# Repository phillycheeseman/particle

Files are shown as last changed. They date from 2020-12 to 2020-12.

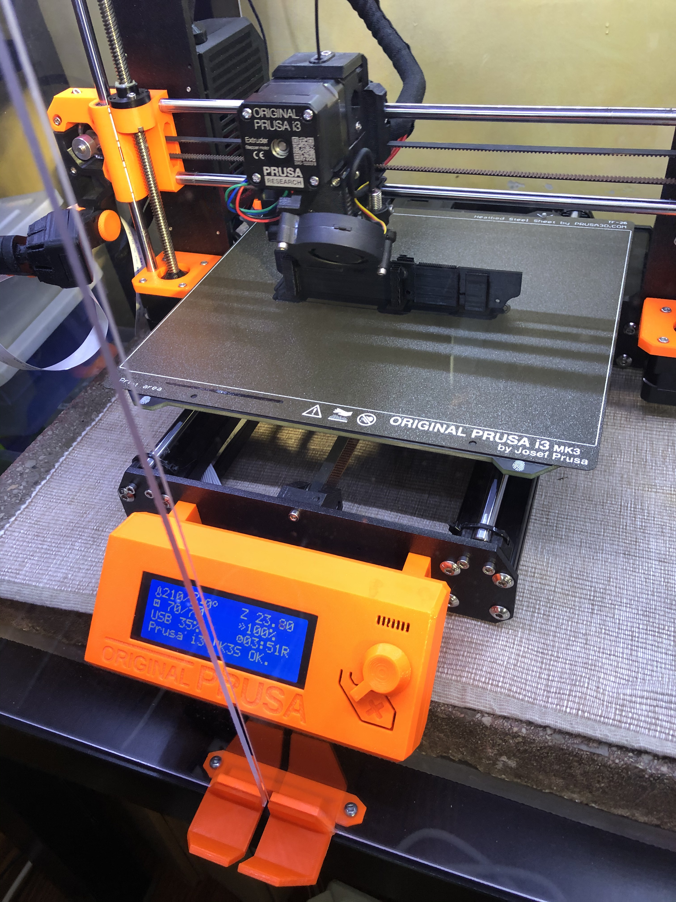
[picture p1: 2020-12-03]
Proto Insert v14/IMG_5619.jpeg

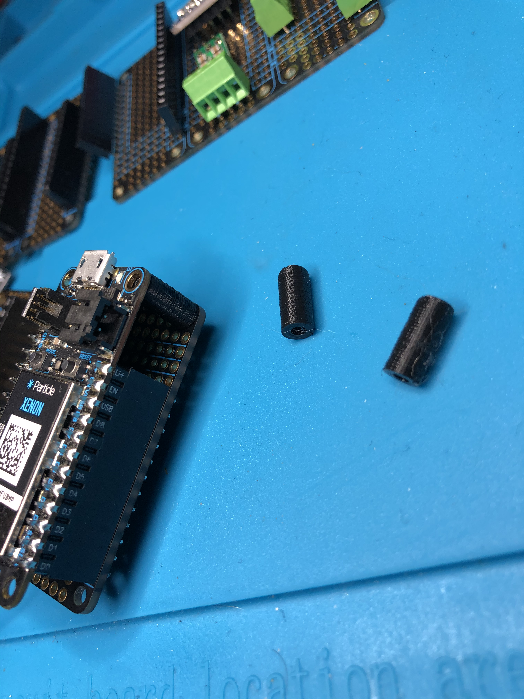
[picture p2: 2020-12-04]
Standoff Spacer/IMG_5630.jpeg

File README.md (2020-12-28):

# particle
Particle.io designs

I am starting this GitHub thread to discuss 3D printing for IoT devices.

There are several project discussions:
- Adapter Plates for commercial Project Boxes
- Header Spacer for supporting Featherwings to Protoboards and Carrier Boards
- 3D printed Project Boxes for indoor use
- 3D printed Project Boxes for outdoor or extreme conditions
- Misc topics as they come up!

This is a work in progress - I am open to suggestions and ideas!
philly

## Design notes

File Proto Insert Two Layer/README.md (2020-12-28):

Divide and Conquer

I was having issues printing the adapter plate; the file was taking too long to print, cleaning the support material was time consuming and the threads in the standoffs were never accurate. After many hours of thought, trial and error I realized there was a better way - 3D printing is an art as much as a science.

My first approach was to print the plate on the long thin edge because there were top standoffs and bottom standoff supports. Printing this required support material and meant printing the entire plate as one file; any changes required entirely reprinting the plate. 

So I ‘cut’ the plate horizontally in two with Fusion, separating the top and bottom elements of the design.

The bottom plate is mirrored to the top plate with the battery compartment. Edges in the bottom plate align with the edges in the top plate battery cutout. The top plate keeps the bottom plate down and secure. I also added a slot for the cellular antenna on the bottom plate; after much trial and error I crafted it so that the top plate becomes the roof of the antenna slot.

The top plate design didn’t change much but I did discover a very cool feature of the Prusa Slicer (and I’m sure other slicers). When slicing the .stl file one can set a layer to pause the print for a color change. In my case I was able to print the top plate base layer white (Prusament PETG Signal White) and the top layer black (Prusament PETG Jet Black). I set the divide point just below the logo layer so that the logo is white on a black mounting plate. So cool!

Truly the amount of work that went into the final design is overkill for my specific case but I see this as an easy way to prototype the idea for other uses. One can learn a lot on a simple project such as this. And the many great ideas added by the community on this thread will help to build the next phase of the design.

I have included the .stl and .f3d files with photos on the GitHub page. As always please enjoy.

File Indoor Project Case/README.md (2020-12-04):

# particle
Particle.io Indoor Project Case

In the first thread I began to explore the use of an adapter plate to mount Particle IoT devices and protoboards to commercially available project cases such as the Big Red Box. The next logical step is to 3D print the entire case!

In making a custom project box there are several considerations:
- Why do it? What are the benefits of a custom case?
- What environmental conditions will the case experience: wet/dry/muddy/clean?
- Will it be in direct sunlight?
- What temperature ranges will the case be subjected to
- What mechanical stresses or forces will the case be expected to support?
- How big should it be?
- What texture or material properties are you looking to achieve?
- How long will it take to print?

I am by no means an expert so I am totally open to suggestions as this thread progresses but I have learned a thing or two and I have a dozen failed attempts to prove it! The best part about 3D printing though is the cost: this case was about $7 in PETG Prusament filament - you could use cheaper brands or use PLA in bulk which is half the price here in Canada. Either way it’s cheap enough that I can try stuff out without too great a penalty. And each iteration only adds to the repertoire of available designs - it just gets better and better each try. 
The first question to ask is why do this? I think there are several reasons to make a custom project case:
Custom sizing: I could never seem to find a commercial case that physically fit both the particle.io IoT device and the final installation space at the same time. It was always too big, small or tall to be useful and don’t get me started on the ugly industrial design look of commercial boxes.
Cost: In small quantities, I can produce a case that’s even cheaper than purchasing one online. If I was making ten thousand cases that’s different but for a few boxes printing on demand is ideal. Yes there was an initial outlay ($1500+-) but the Prusa MK3S has become the second most useful machine in the house (Nespresso coffee maker is still no. 1). I print stuff for my wife all the time - this alone is worth the brownie points! If I amortize the IoT usage only, the cost of owning a 3D printer is minimal. Print On Demand services are available if you don’t have a printer but this is cost prohibitive especially for trial and error.
Custom look and feel: nothing looks cooler than a project case with your logo embossed into the design! One can choose the material, colour and style to fit the individual project; the case doesn’t have to be rectangular.
Product Design: If I want to sell or market a product in the IoT space I can’t rely on commercial project boxes. To create a production mold is incredibly expensive and only useful when stamping out large quantities. I firmly believe that at a small scale I can produce a product worth selling yet sourced locally.

Once you’ve committed to building a custom case there are few questions that will dictate the design. The first question I consider is what conditions the box will be expected to perform in? When I’m working on flood management tools I need a water tight box that will be subjected to mud, sand and the odd misguided shovel. But when I’m building a garage sensor system I only need something to keep out dust. On my sailboat, the IoT cases need to be lightly water tight and only reasonably secure - if it’s really underwater in the cockpit I’ve got much much bigger issues at that point!

In this thread I will explore the easiest example: an indoor installation in a garage. This project box needs to be dust and dirt proof, provide secure wire entry points for power and sensor cables and have easy access to the IoT device inside.

Since this unit will be installed in a garage it will not be subjected to sunlight which requires a UV protective filament or spray coating. It also won’t hit sunlight temperatures which can melt the case.

As this case didn’t need to be water tight I decided to go with a ‘snap fit’ design. The lid pops on/off with a snap fit lip that keeps the top in place. In fact it works so well I had to build into the back top edge an opening to pry the lid off when needed otherwise it couldn’t easily taken apart once snapped into place. It also saves on screws or other fasteners which add to cost and complexity. It’s also faster to pop off the lid than unscrew the top - after five or ten times of opening the box this point is not lost on me.

I designed two flanges to screw mount the box. The side has a cable gland that allows a clean and protective way to feed power and sensor cables into the device. The front has openings for a Flame sensor, PIR sensor and LUX sensor. The PIR sensor required designing mounting standoffs while the LED sensors are fitted into place. I did try using commercial LUX and Flame breakout boards but they required mounting standoff posts as well and the design became excessive and expensive.

The Boron is mounted to a Carrier Board which is mounted to the case using M3 screws. There is also a protoboard that sensors and 5v devices plug into so that had to fit in as well. The overall design had to rugged but not incredibly so - once installed it wouldn’t move much. 

The material could be any color; I went with grey because I ran out black. I used PLA for this installation because it was cheap and well within the limits of temperature and mechanical stress. For this installation I could use PETG as it’s a bit stronger but slightly more brittle as I has discovered.

The overall case has a ‘filleted’ edge to make it softly rounded. The standoffs also have a filleted edge on the bottom where it connects to the case to provide strength to the post otherwise I found they can easily shear off.

I added my logo to the top of the case. There is nothing more rewarding than seeing your custom design brought to life - it almost looks professional.

The last thing to consider is the time it takes to print the box. The final design takes about 14+ hours to print on my machine - even longer if I want quiet stealth mode. This may seem crazy BUT consider this: if I ordered a case from Digikey or AliExpress it would take a couple days or longer to get to me. With this process I push print in the evening and by the time I wake up in the morning it’s arrived at my door (in a sense) and the delivery is free.

I am convinced that one day in the not too distant future two kids will be playing with a toy and one will say, “Did you know that back in the day they used to make these in factories overseas and ship them in?” The other child will say, “No way! That’s crazy…” as she presses print on her home maker box and spits out custom fitted running shoes.

In the end I was able to create the case I wanted and needed (see photos). I can make as many as I want and I can customize to the sensors I need. Well worth the effort!

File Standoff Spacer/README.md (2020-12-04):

# particle
Particle.io Standoff Spacer

This is a design for a "standoff spacer" that fits between a Gen3 device such as a Boron to the protoboard or carrier board it is fitted to. This spacer accounts for the header male and female heights (11mm) and has a 5mm diameter which is just enough to provide support yet provides a way to secure the board tightly. The mounting holes are M2.5 and the thread goes right through so it can be screwed in from above and below.

Simple but effective!
philly

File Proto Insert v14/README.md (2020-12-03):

# particle
Particle.io designs

I am starting this thread to discuss 3D printing adapter plates for IoT devices so they can be mounted inside a project box. I am open to suggestions and questions as I hope this thread is a useful starting place for others.

I started making IoT devices with particle.io in 2017 to measure Lake Ontario flooding and to monitor/control local pumps. I quickly discovered that while the coding was easy with my background as a software developer and the electronic skills to assemble a working unit I could learn from the Interwebs, the biggest stumbling block was the project case for housing the device. For flood work I was looking for a ‘water tight’ case; I wasn’t lowering these units to the depths of the ocean but they were going to be wet and perhaps under a few inches of water and in somewhat harsh conditions.

As I did have some prerequisites the range of available choices was rather small. The project box had to be water tight, the perfect size (not too large, not too small), sturdy enough for real world use, readily available and most importantly as cheap as possible. There are “Otter Boxes” that are amazingly rugged and water tight - they are also insanely expensive! I just couldn’t justify paying more for the container than the parts within. I settled on the SparkFun's 'Big Red Box’ (PRT-11366 https://www.digikey.com/en/products/detail/sparkfun-electronics/PRT-11366/7393713). At $15 Canadian they were a decent choice - water tight, large enough to hold a Boron on a Particle FeatherWing Tripler protoboard with the all wiring etc. While not perfect these boxes would work but there was still one issue I kept coming up against.

I have tried many project boxes and I discovered rather quickly that none of the companies talk to each other - none of the holes align! Every protoboard, breakout board and microcontroller seemed to have different mounting holes. The Adafruit FeatherWing standard has helped to make the process easier but the mounting points simply do not match any cases’ internal standoffs or mounting holes.

After a ton of research and a few years of wavering I broke down and purchased a 3D printer. I got the kit version of the Prusa MK3S; I had a fantastic time assembling it and I saved $500 by doing it myself. It was surprisingly easy to print objects I could download from Thingiverse and other 3D file sharing sites. The file format commonly used is .STL and there are many ways of viewing this file type. To create my own project cases and adapters I would have to learn a 3D drawing application. With the help of YouTubes I taught myself enough Fusion360 to start creating printable things.

The first attempt at 3D IoT printing, and the point of this thread, was to make a ‘protoboard adapter’ plate to mount the FeatherWing Tripler inside the Big Red Box. I needed the adapter plate to have mounting holes that match the box, standoffs and mounting holes for the FeatherWing Tripler and a way to secure the LiPo and the antenna from rattling around. I also wanted a parametric design which means assigning variables to measurements so changes in width, height and thickness are cascaded down through the object.

The .stl file I have attached is the product of many iterations and attempts. While the protoboard sizes and mounting hole positions are openly available on the Adafruit site, there were many challenges to the final design. I came to the following conclusions:
- Plate thickness is 2mm. Anything more is overkill.
- Standoffs for mounting the protoboard are 8mm in height.
- All mounting positions are represented in the “sketch” but only the mounting standoffs needed for this design were extruded.
- Mounting holes on Particle and Adafruit boards require M2.5 screws. I use nylon screws from adafruit.com.
- Some protoboards require M3 mounting  screws.
- I use the thread option in Fusion360 to create threaded mounting holes ready for the screws. It was a trial and error situation getting the right sizes of threads to match the scores I am using but in the end it does work.
- To save time in printing I ‘hollowed out’ areas on the plate that didn’t add any function.
- I added underside walls too hold the LiPo so it would not rattle around.
- I added a tunnel for the antenna to slip into.

While it takes 6 hours to print each plate (this can be drastically reduced by tweaking settings) the final print cost is $1.44 for the PLA filament and maybe a dime for electricity (Canadian). This design is particular to the Big Red Box but it can easily adapt to any project case. It has opened up many more options and makes the final IoT project so much more complete.

The next thread, which I will keep separate, is my exploration into designing and printing the entire project case on demand and at a fraction of the cost of buying one.

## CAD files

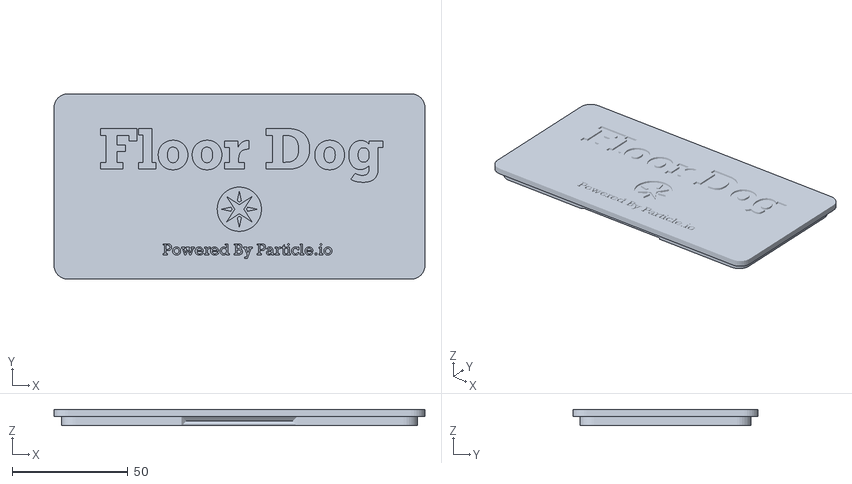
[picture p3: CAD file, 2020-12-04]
Indoor Project Case/Sensor Case v11 Top.stl
160.0 x 80.0 x 7.00

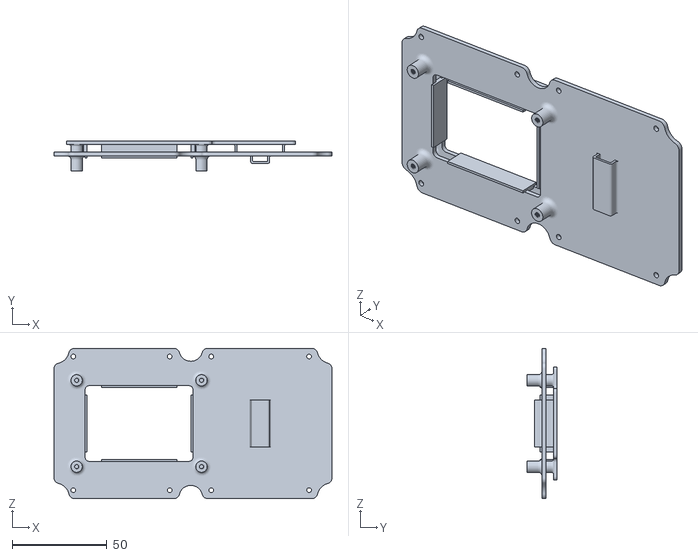
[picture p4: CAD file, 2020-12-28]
Proto Insert Two Layer/Proto Insert Two Layer.stl
147.1 x 16.0 x 79.5

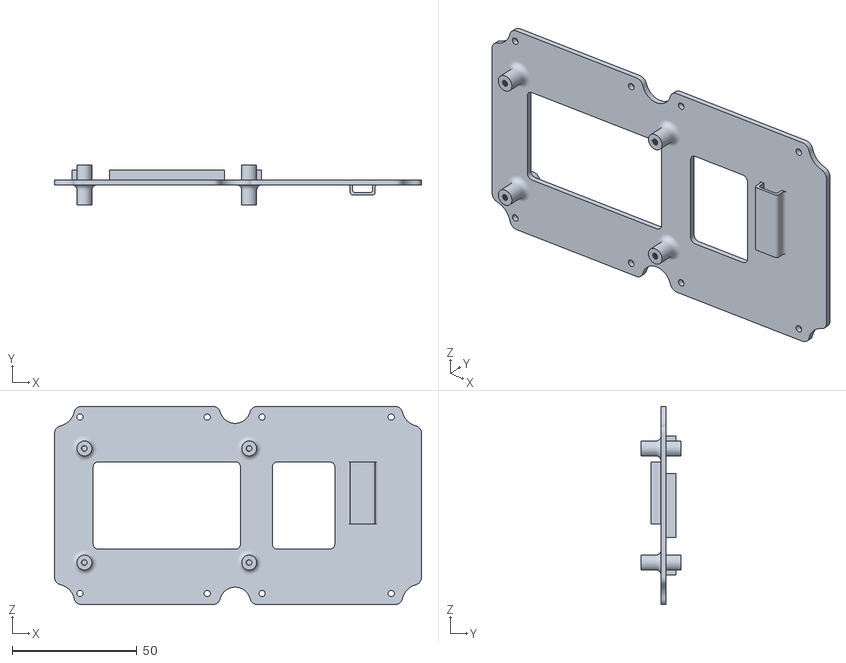
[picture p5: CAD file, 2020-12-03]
Proto Insert v14/Proto Insert v14 v1 v14.stl
147.1 x 16.0 x 79.5

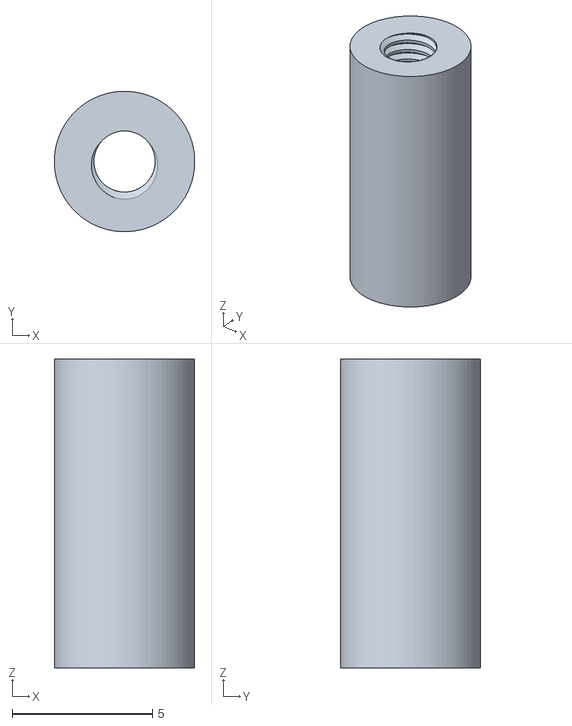
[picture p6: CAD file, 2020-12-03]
Standoff Spacer/Standoff Spacer v1 v1.stl
5.00 x 5.00 x 11.0

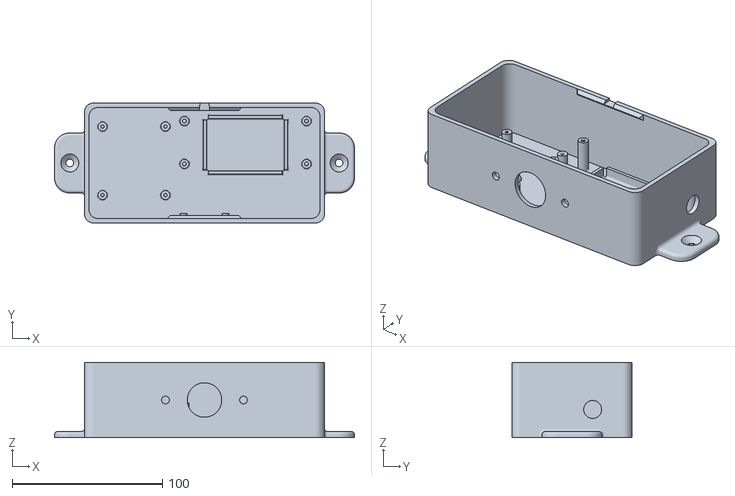
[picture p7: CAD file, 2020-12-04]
Indoor Project Case/Sensor Case v11 Bottom.stl
200.0 x 80.0 x 50.0

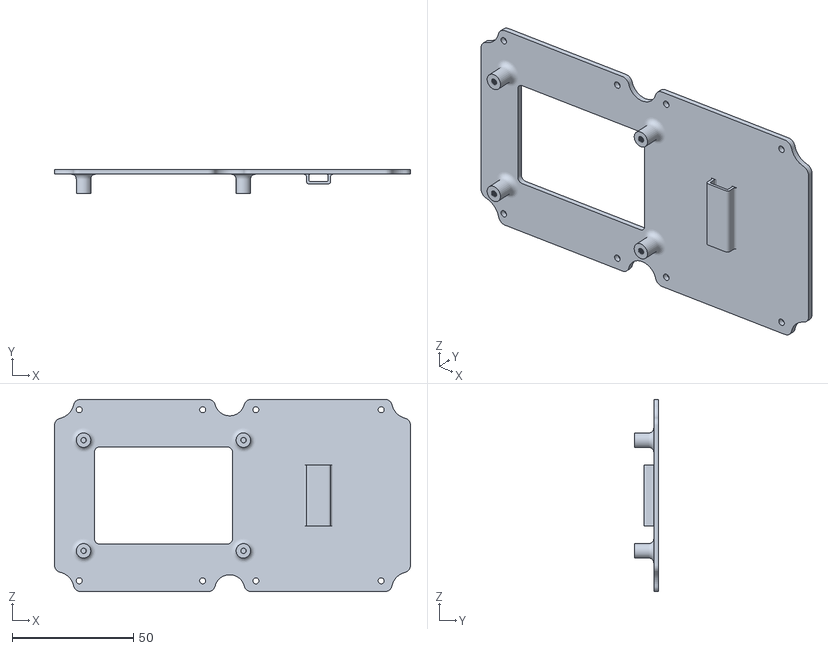
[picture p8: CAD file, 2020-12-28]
Proto Insert Two Layer/Proto Insert Top Layer.stl
147.1 x 10.0 x 79.5

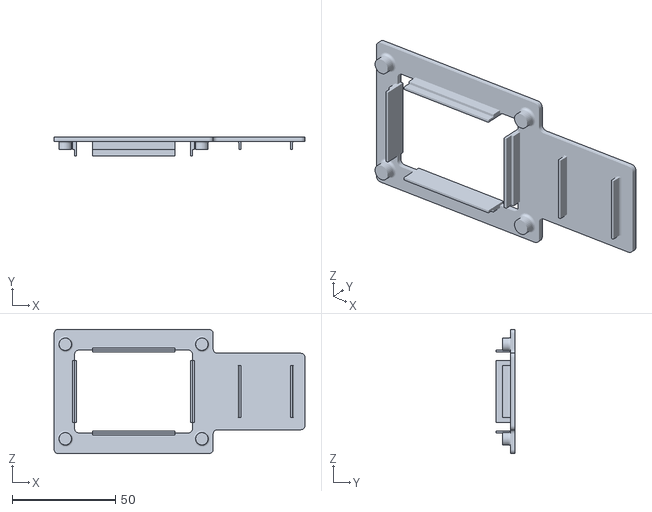
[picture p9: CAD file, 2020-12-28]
Proto Insert Two Layer/Proto Insert Bottom Layer.stl
121.4 x 9.00 x 60.0

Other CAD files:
Indoor Project Case/Sensor Case v11.f3d
Proto Insert Two Layer/Proto Insert Layer Part.f3d
Proto Insert v14/Proto Insert v14 v1 v14.f3d
Standoff Spacer/Standoff Spacer v1 v1.f3d
